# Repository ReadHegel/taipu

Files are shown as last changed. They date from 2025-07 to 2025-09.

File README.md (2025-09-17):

# Taipu

Taipu is a highly ergonomic, split mechanical Bluetooth keyboard I designed as a DIY project. My goal was to make it look 'barebone' with as much components visible just because I like it. I designed it with Polish language users in mind.

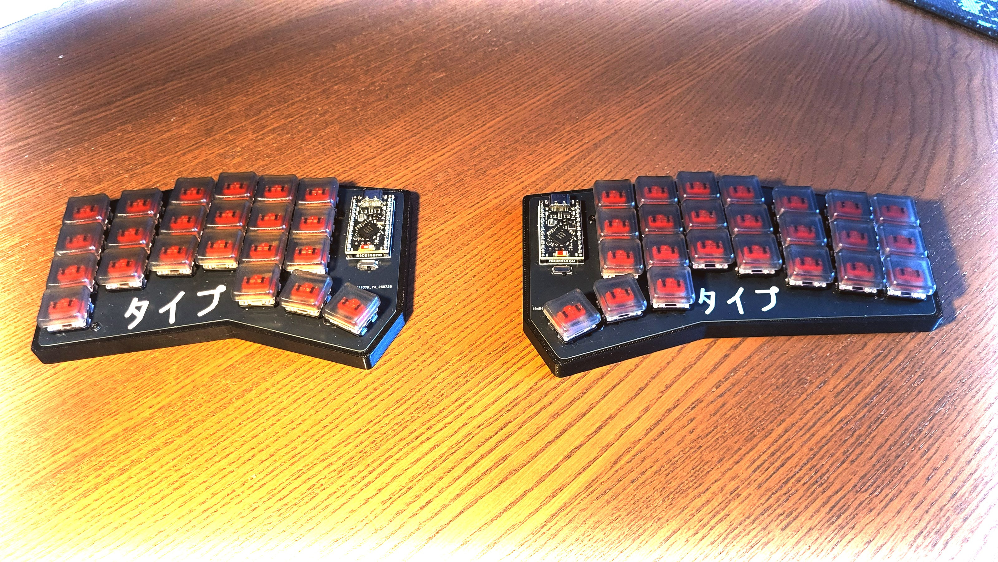
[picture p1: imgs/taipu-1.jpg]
 

## Features

- Ergonomic Split Design

- Highly Customizable ZMK Layout (https://nickcoutsos.github.io/keymap-editor/)

- Wireless Connectivity

- Barebones Aesthetic

- Polish-Language Optimized

###  Ergogen 

In the `./ergogen/` directory contain the ergogen configuration of taipu. It generates the pcb with out traces and stl files needed to 3d print the case. The kicad handles cicurity of pcb (`./kicad/` directory).

### Firmware 

For firmware I have use ZMK framework. The configuration is avaiable `./taipu-zmk-config/`. Ready compiled firmware files one can find at the Github Action page on the `taipu-zmk-config` submodule.

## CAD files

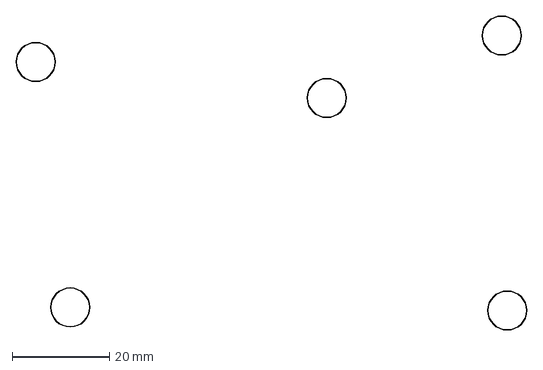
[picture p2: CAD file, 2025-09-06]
ergogen/output/outlines/left_mounting_standoff.dxf
105.0 x 64.6 mm

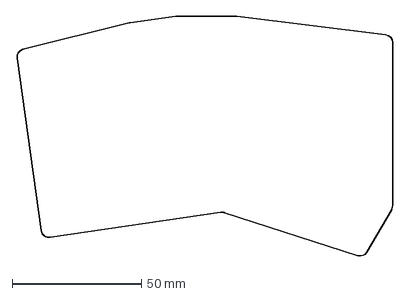
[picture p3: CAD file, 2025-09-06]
ergogen/output/outlines/board_left_with_buffer.dxf
145.5 x 93.0 mm

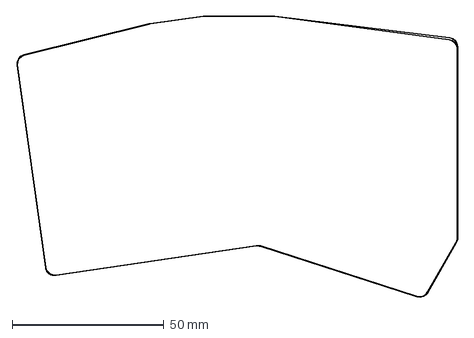
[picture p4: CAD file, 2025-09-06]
ergogen/output/outlines/combo_buffer_left.dxf
145.5 x 93.0 mm

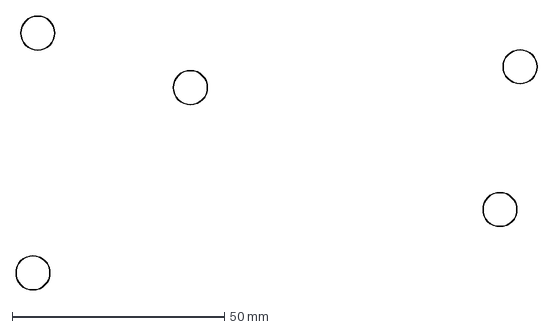
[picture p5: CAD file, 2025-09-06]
ergogen/output/outlines/right_mounting_standoff.dxf
122.9 x 64.6 mm

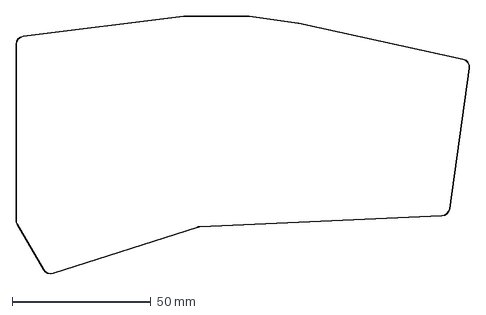
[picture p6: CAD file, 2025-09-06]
ergogen/output/outlines/board_right_with_buffer.dxf
163.3 x 93.0 mm

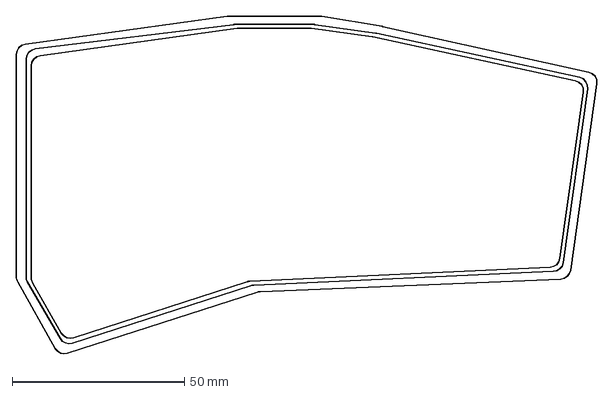
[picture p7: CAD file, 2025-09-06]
ergogen/output/outlines/inspect_wall_right.dxf
168.8 x 98.4 mm

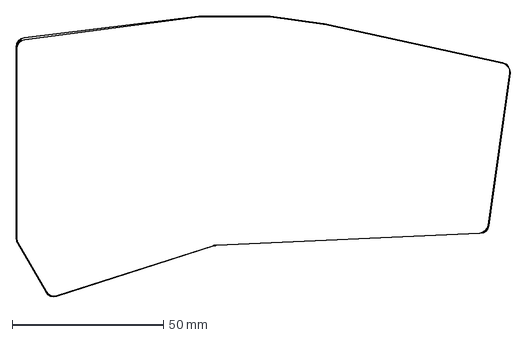
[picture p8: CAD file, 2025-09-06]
ergogen/output/outlines/combo_buffer_right.dxf
163.3 x 93.0 mm

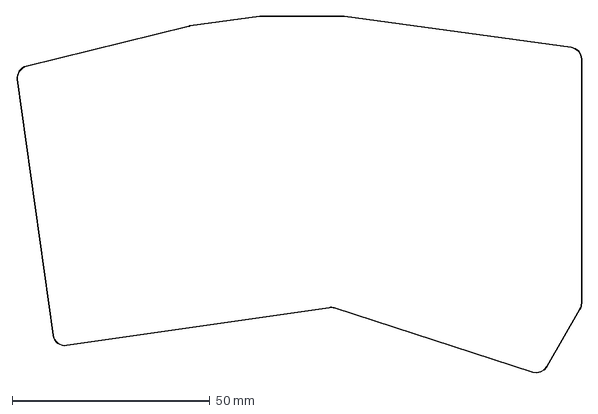
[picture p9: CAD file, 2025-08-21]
ergogen/output/outlines/xs_board_left.dxf
142.7 x 90.4 mm

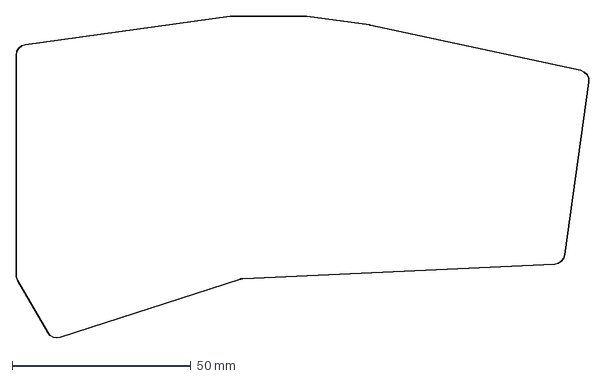
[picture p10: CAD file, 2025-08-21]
ergogen/output/outlines/xs_board_right.dxf
160.6 x 90.4 mm

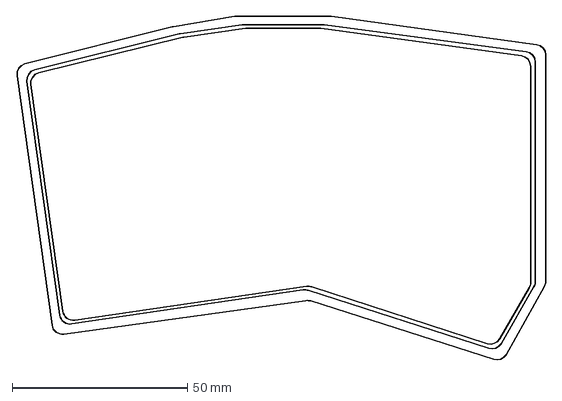
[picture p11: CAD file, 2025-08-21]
ergogen/output/outlines/inspect_wall_left.dxf
151.0 x 98.4 mm

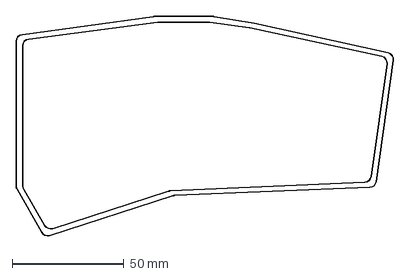
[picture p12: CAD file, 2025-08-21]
ergogen/output/outlines/case_wall_right.dxf
168.8 x 98.4 mm

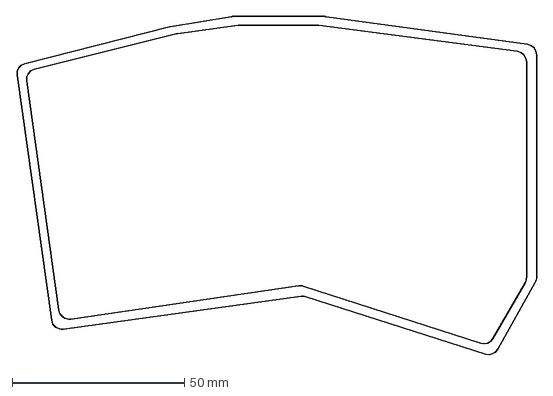
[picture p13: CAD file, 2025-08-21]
ergogen/output/outlines/case_wall_left.dxf
151.0 x 98.4 mm

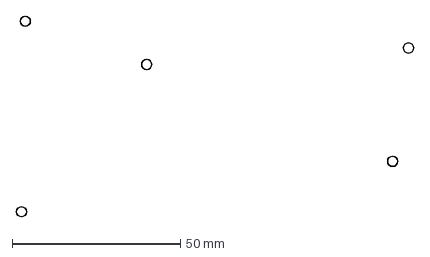
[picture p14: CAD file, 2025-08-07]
ergogen/output/outlines/right_mounting.dxf
117.9 x 59.6 mm

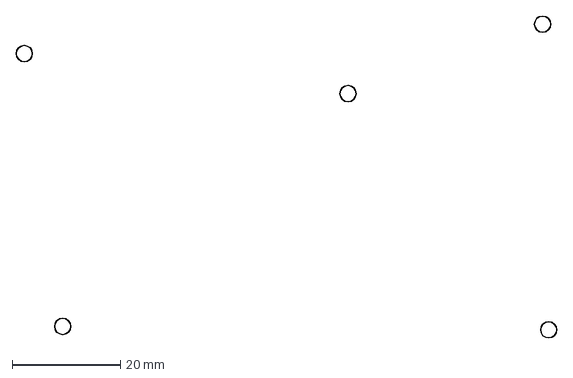
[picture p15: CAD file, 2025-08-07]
ergogen/output/outlines/left_mounting.dxf
100.0 x 59.6 mm

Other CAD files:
ergogen/output/outlines/xl_board_left.dxf
ergogen/output/outlines/xl_board_right.dxf
ergogen/output/outlines/combo.dxf
ergogen/output/outlines/combo_right.dxf
ergogen/output/outlines/board_left.dxf
ergogen/output/outlines/board_right.dxf
ergogen/output/outlines/combo_left.dxf
ergogen/output/outlines/keys.dxf
ergogen/output/outlines/raw.dxf

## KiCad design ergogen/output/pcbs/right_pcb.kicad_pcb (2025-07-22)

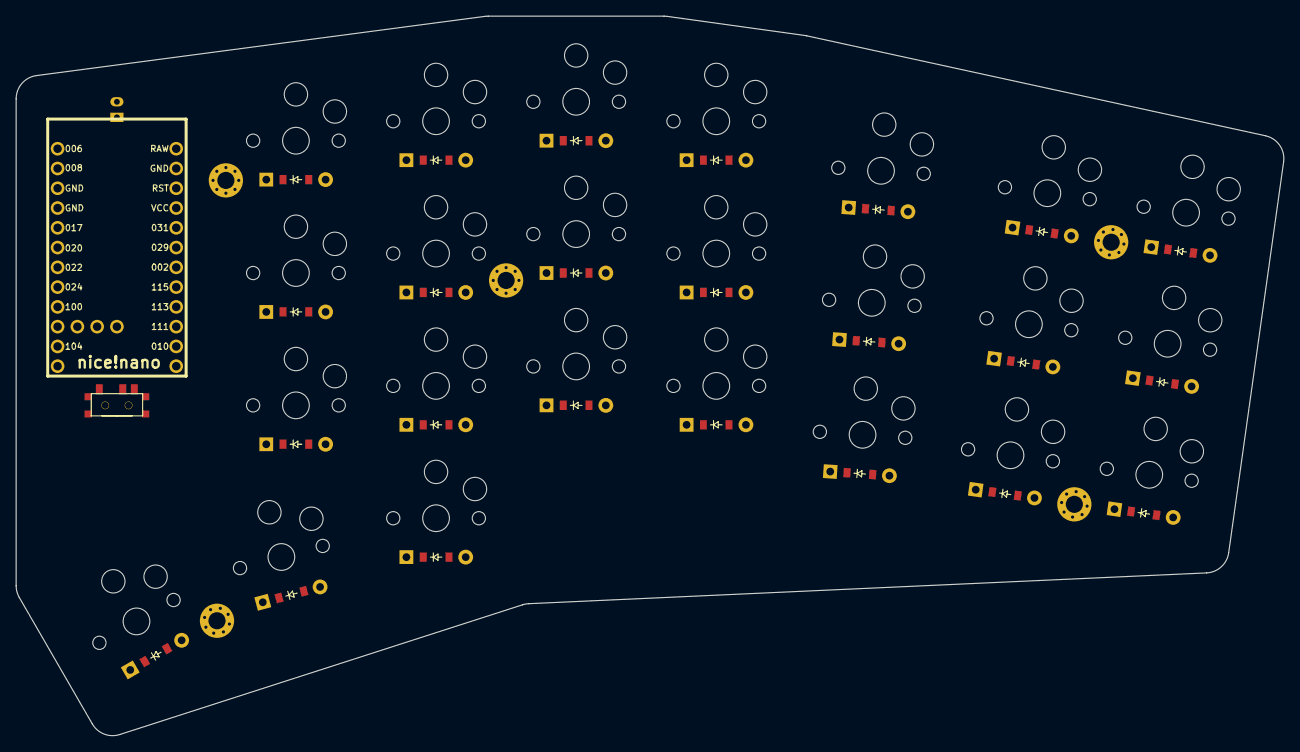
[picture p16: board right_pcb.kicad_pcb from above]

Board: 2 copper layers, 162.9 x 92.4 mm, 56 parts (0 on the bottom side), 38 nets, no tracks yet.

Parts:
D1, D2, D3, D4, D5, D6, D7, D8, D9, D10, D11, D12, D13, D14, D15, D16, D17, D18, D19, D20, D21, D22, D23, D24: ComboDiode
JST1: JST_PH_S2B-PH-K_02x2.00mm_Angled
MCU1: nice_nano
S1, S2, S3, S4, S5, S6, S7, S8, S9, S10, S11, S12, S13, S14, S15, S16, S17, S18, S19, S20, S21, S22, S23, S24: PG1350
T1: SPDT_C128955
_1, _2, _3, _4, _5: MountingHole_2.2mm_M2_Pad_Via

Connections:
GND: JST1.2, MCU1.3, MCU1.4, MCU1.23
P002: D1.1, D4.1, D7.1, D10.1, D13.1, D17.1, D20.1, MCU1.18
P011: MCU1.10, S17.1, S18.1, S19.1, S23.1
P017: MCU1.5, S1.1, S2.1, S3.1
P020: MCU1.6, S4.1, S5.1, S6.1
P022: MCU1.7, S7.1, S8.1, S9.1
P024: MCU1.8, S10.1, S11.1, S12.1
P029: D2.1, D5.1, D8.1, D11.1, D14.1, D18.1, D21.1, MCU1.19
P031: D3.1, D6.1, D9.1, D12.1, D15.1, D19.1, D22.1, MCU1.20
P100: MCU1.9, S13.1, S14.1, S15.1, S16.1
P104: MCU1.11, S20.1, S21.1, S22.1, S24.1
P115: D16.1, D23.1, D24.1, MCU1.17
RAW: MCU1.24, T1.2
mirror_clone_outer_bottom: D1.2, S1.2
mirror_clone_outer_home: D2.2, S2.2
mirror_clone_outer_top: D3.2, S3.2
mirror_index_bottom: D17.2, S17.2
mirror_index_home: D18.2, S18.2
mirror_index_mod: D16.2, S16.2
mirror_index_top: D19.2, S19.2
mirror_inner_bottom: D20.2, S20.2
mirror_inner_home: D21.2, S21.2
mirror_inner_top: D22.2, S22.2
mirror_layer_cluster: D23.2, S23.2
mirror_middle_bottom: D13.2, S13.2
mirror_middle_home: D14.2, S14.2
mirror_middle_top: D15.2, S15.2
mirror_outer_bottom: D4.2, S4.2
mirror_outer_home: D5.2, S5.2
mirror_outer_top: D6.2, S6.2
mirror_pinky_bottom: D7.2, S7.2
mirror_pinky_home: D8.2, S8.2
mirror_pinky_top: D9.2, S9.2
mirror_ring_bottom: D10.2, S10.2
mirror_ring_home: D11.2, S11.2
mirror_ring_top: D12.2, S12.2
mirror_space_cluster: D24.2, S24.2
pos: JST1.1, T1.1

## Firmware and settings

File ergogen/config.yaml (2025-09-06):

units:
  # Proxy Spacing Variables
  # cx = 18, cy = 17
  kx: cx
  ky: cy
  # Padding Variables
  px: kx + 5
  py: ky + 5
  # Padding Variables with buffer for 3d print
  pxb: kx + 5.2
  pyb: ky + 5.2
  # Double padding for case
  dpx: kx + 9
  dpy: ky + 9
  # Smaller padding for pcb stand
  spx: kx + 3
  spy: ky + 3


  case_bottom_thick: 2
  pcb_height: 1.5

  # 1.5 (radius) <=> 3mm (diameter) 
  # (2mm for M2 screw + 0.7 mm for screw insert + 0.3 mm for printing buffer) 
  screw_rad: 1.5 
  screw_standoff_rad: 4

  # screw insert are 3 milimeters height
  pcb_bottom_height: case_bottom_thick + 5

  # this way the wall should be at the same level what pcb is 
  case_wall_height: pcb_bottom_height + pcb_height + 0

  $default_width: cx
  $default_height: cy
points:
  zones:
    matrix:
      # Fix placement on KiCAD sheet.
      anchor:
        shift: [70, -150]
      key:
        padding: 1ky
        spread: 1kx
      columns:
        clone_outer:
          key:
            splay: 8
            asym: clone
            column_net: P017
          rows.mod.skip: true
        outer:
          key.splay: 0
          key.column_net: P020
          rows.mod:
            key.skip: true
            asym: source
        pinky:
          key.splay: -4
          key.column_net: P022
          rows.mod.skip: true
        ring:
          key.splay: -4
          key.column_net: P024
          key.stagger: 5
          rows.mod.skip: true
        middle:
          key.stagger: 2.5
          key.column_net: P100
          rows.mod.skip: true
        index:
          key.column_net: P011
          rows.mod.column_net: P100
          key.stagger: -2.5 
        inner:
          key.stagger: -2.5
          key.column_net: P104
          rows.mod.skip: true
      rows:
        mod:
          row_net: P115
        bottom:
          row_net: P002
        home:
          row_net: P029
        top:
          row_net: P031
    thumbs:
      key:
        padding: 1ky
        spread: 1kx
      anchor:
        ref: matrix_inner_mod
        shift: [2, -2]
      columns:
        layer:
          key:
            column_net: P011
            splay: -15
            shift: [0, -0.5]
        space:
          key:
            column_net: P104
            splay: -15
            shift: [3, -3]
      rows:
        cluster:
          row_net: P115
  mirror: &mirror
    ref: matrix_inner_top
    distance: 5kx
outlines:
  raw:
    - what: rectangle
      where: true
      size: [kx, ky]
  keys:
    - what: rectangle
      where: true
      size: [kx-0.5,ky-0.5]
  board_left:
    - what: polygon
      operation: stack
      points:
        - ref: thumbs_space_cluster
          shift: [0.5px, -0.5py]
        - ref: thumbs_space_cluster
          shift: [0.5px, 0.5py]
        - orient: 30
          shift: [0px,3py]
        - ref: matrix_middle_top
          shift: [0.5px,0.5py]
        - ref: matrix_middle_top
          shift: [-0.5px,0.5py]
        - ref: matrix_ring_top
          shift: [-0.5px,0.5py]
        - ref: matrix_outer_top
          shift: [-0.5px,0.5py]
        - ref: matrix_outer_mod
          shift: [-0.5px,-0.5py]
        - ref: matrix_index_mod
          shift: [-0.5px, -0.5py]
      fillet: 3
  board_left_with_buffer:
    - what: polygon
      operation: stack
      points:
        - ref: thumbs_space_cluster
          shift: [0.5pxb, -0.5pyb]
        - ref: thumbs_space_cluster
          shift: [0.5pxb, 0.5pyb]
        - orient: 30
          shift: [0pxb,3pyb]
        - ref: matrix_middle_top
          shift: [0.5pxb,0.5pyb]
        - ref: matrix_middle_top
          shift: [-0.5pxb,0.5pyb]
        - ref: matrix_ring_top
          shift: [-0.5pxb,0.5pyb]
        - ref: matrix_outer_top
          shift: [-0.5pxb,0.5pyb]
        - ref: matrix_outer_mod
          shift: [-0.5pxb,-0.5pyb]
        - ref: matrix_index_mod
          shift: [-0.5pxb, -0.5pyb]
      fillet: 3
  xl_board_left:
    - what: polygon
      operation: stack
      points:
        - ref: thumbs_space_cluster
          shift: [0.53dpx, -0.5dpy]
        - ref: thumbs_space_cluster
          shift: [0.52dpx, 0.48dpy]
        - orient: 30
          # manual intervention xD
          # 3py + 0.5 * 4 = 3 * (17 + 5) + 2 = 68 
          shift: [0,68]
        - ref: matrix_middle_top
          shift: [0.5dpx,0.52dpy]
        - ref: matrix_middle_top
          shift: [-0.5dpx,0.52dpy]
        - ref: matrix_ring_top
          shift: [-0.5dpx,0.5dpy]
        - ref: matrix_outer_top
          shift: [-0.52dpx,0.5dpy]
        - ref: matrix_outer_mod
          shift: [-0.52dpx,-0.52dpy]
        - ref: matrix_index_mod
          shift: [-0.4dpx, -0.54dpy]
      fillet: 3
  xs_board_left:
    - what: polygon
      operation: stack
      points:
        - ref: thumbs_space_cluster
          shift: [0.5spx, -0.5spy]
        - ref: thumbs_space_cluster
          shift: [0.5spx, 0.5spy]
        - orient: 30
          shift: [0px,2.96py]
        - ref: matrix_middle_top
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

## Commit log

2025-07-20 mounting holes and net
    [kicad.kicad_pcb, left_pcb.kicad_pcb, right_pcb.kicad_pcb]
2025-07-22 better batery placement
    [left_pcb.kicad_pcb, right_pcb.kicad_pcb]
2025-07-25 add logo
    [left_pcb-B_Cu.gbr, left_pcb-B_Mask.gbr, left_pcb-B_Paste.gbr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]
2025-08-07 drills and simple case
    [left_case.stl, left_mounting.dxf, left_mounting_standoff.dxf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]
2025-08-13 add zmk
    [left_case.stl, left_mounting.dxf, right_case.stl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]
2025-08-13 repo refactor
    [board_left.dxf, board_right.dxf, combo.dxf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]
2025-08-21 add pcb standoff next to the wall
    [case_wall_left.dxf, case_wall_right.dxf, inspect_wall_left.dxf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]
2025-09-06 fix case buffer for 3d printing
    [board_left_with_buffer.dxf, board_right_with_buffer.dxf, combo_buffer_left.dxf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]
2025-09-17 add readme
    [kicad.kicad_sch, left_case.stl, left_pcb.kicad_pcb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]
